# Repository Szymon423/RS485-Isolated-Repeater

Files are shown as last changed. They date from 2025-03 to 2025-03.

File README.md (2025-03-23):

# RS485 Isolated Repeater

This project is abotut designing an isolated repeater for RS485 communication. As a person who many times had to deal with RS485 communication, I know how important it is to have a repeater in order to extend the communication distance. However, I also know how important it is to have an isolated repeater in order to avoid ground loops and other issues that can arise from non-isolated repeaters. This project is about designing an isolated repeater that can be used to extend the communication distance of RS485 devices. The repeater is designed to be used with a `12..24V` power supply and can be used to extend the communication distance up to 1000 meters. 

> [!IMPORTANT]
> Chad GPT is amazing and made up this trash talk above.

To be honest this is not about extending range of RS485 loop, even though it can be used for that. It is about isolating the RS485 devices which are shitty and can cause problems. 

> [!NOTE]
> I want to help people who made shitty RS485 bus or RS485 devices.

## Tools stack
- Hardware design: `KiCad`
- PCB manufacturing: `JLCPCB`
- Microcontroller code: `Raspberry Pi Pico Extension for VSCode`
- Knowledge: `IDK`

## Hardware
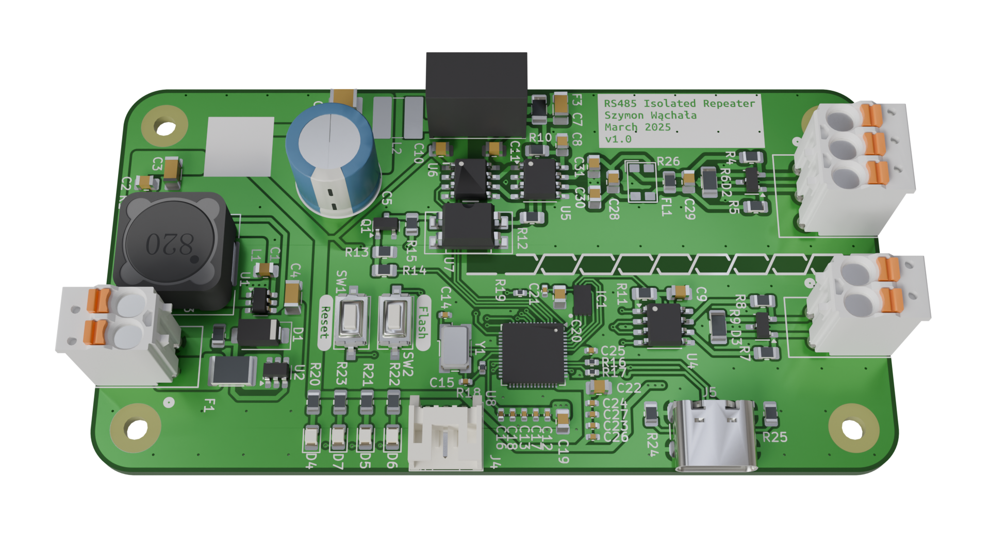
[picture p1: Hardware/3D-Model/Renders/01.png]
PCB render


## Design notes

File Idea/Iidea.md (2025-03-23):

# Must have
 - Single power supply `12..24VDC`
 - One RS485 port must be galvanicly isolated
 - Onboard isolated voltage regulator `3.3VDC`
 - Auto adaptation to: 
    - baudrate `9600..115200 bps`
    - parity `none, even, odd`
    - stop bits `1, 2`
    - data bits `8, 7`
 - LED showing power supply
 - LEDs showing communication direction
 - LED showing errors in communication - both sides are beeing driven in the same time

# Components
 - [Texas Instruments ISO1410DW](https://www.tme.eu/pl/details/iso1410dw/uklady-scalone-rs232-rs422-rs485/texas-instruments/) - isolated RS485 transceiver
 - [Texas Instruments THVD1400DR](https://www.tme.eu/pl/details/thvd1400dr/uklady-scalone-rs232-rs422-rs485/texas-instruments/) - non-isolated RS485 transceiver
 - [AIMTEC AM1S-0303SH30Z](https://www.tme.eu/pl/details/am1s-0303sh30z/przetwornice-dc-dc/aimtec/) - 3.3VDC isolated voltage regulator
 - [Texas Instruments TPS54202DDCR](https://www.tme.eu/pl/details/tps54202ddcr/regulatory-napiecia-uklady-dc-dc/texas-instruments/) - 3.3VDC non-isolated voltage regulator
 - [Raspberry RP2040](https://www.tme.eu/pl/details/sc0914-7/raspberry-pi-embedded/raspberry-pi/ic-rp2040-rp2b2-t-r-500-7-reel/) - microcontroller
 - [Winbond W25Q16JVUXIQ TR](https://www.tme.eu/pl/details/w25q16jvuxiq-tr/pamieci-flash-szeregowe/winbond/w25q16jvuxiq-tr/) - flash memory
 - [Abracon ABM8-272-T3](https://mou.sr/4bnWQzx) - Crystal oscillator
 - [Ferrocore 18uH 0504](https://www.tme.eu/pl/details/dlg-0504-180/dlawiki-smd-mocy/ferrocore/)

# Schematics 

**12..24VDC to 3.3VDC**
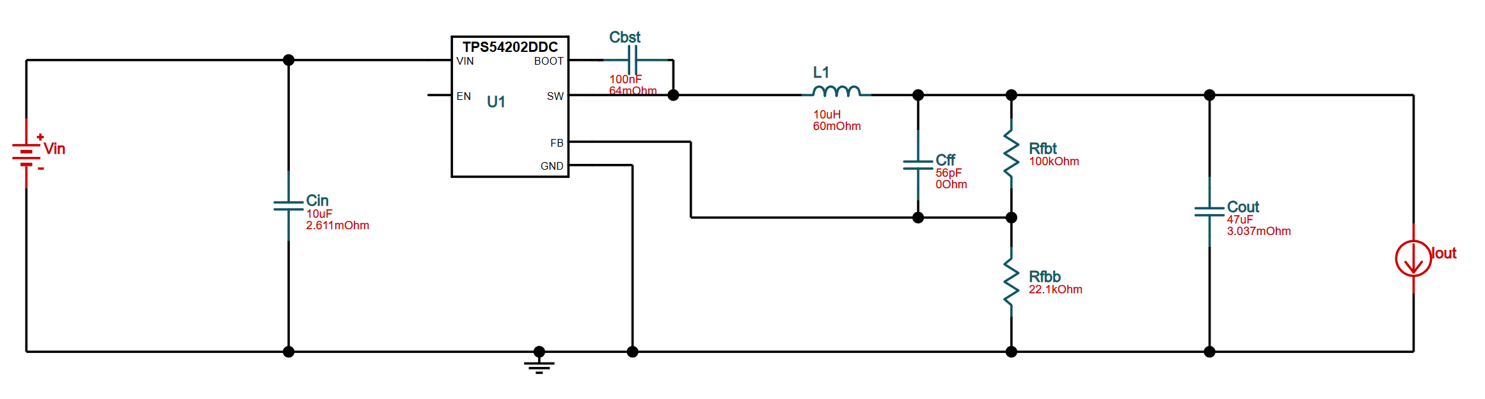
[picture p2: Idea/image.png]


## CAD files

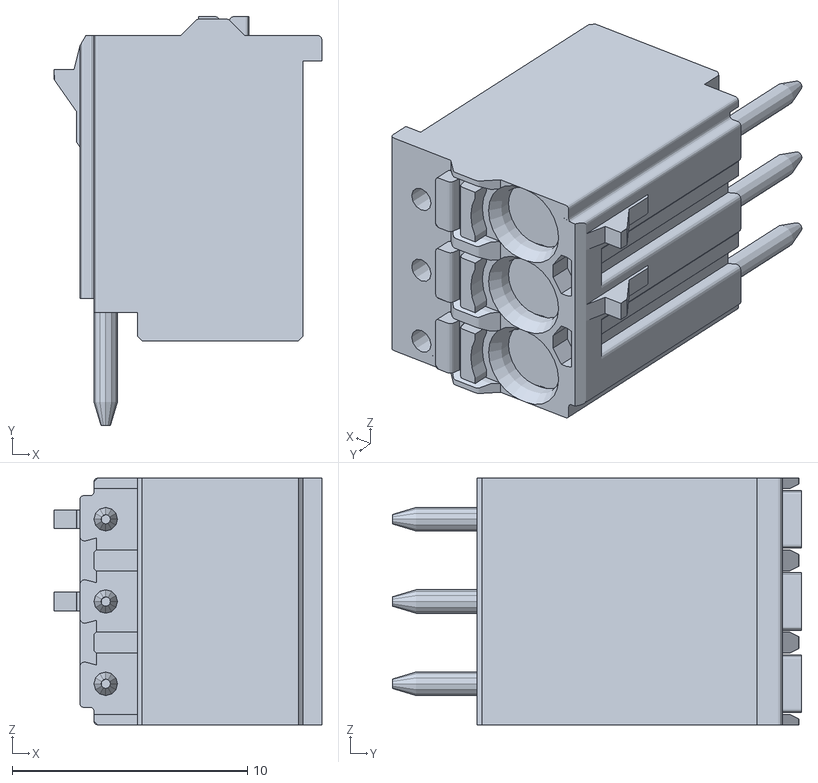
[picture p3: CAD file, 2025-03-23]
Hardware/3D-Model/Assets/2091-1173.obj
11.4 x 17.4 x 10.5

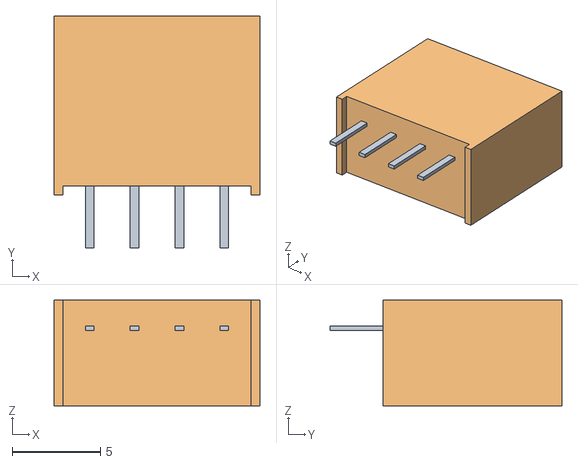
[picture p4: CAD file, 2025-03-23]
Hardware/3D-Model/Assets/AM1S-Z.obj
11.7 x 13.1 x 6.00
obj1
obj2

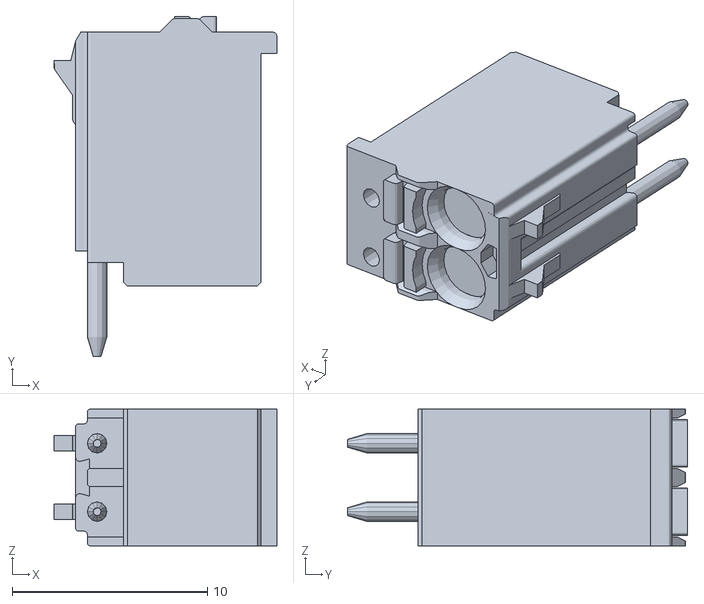
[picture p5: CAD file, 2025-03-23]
Hardware/3D-Model/Assets/2091-1172.obj
11.4 x 17.4 x 7.00

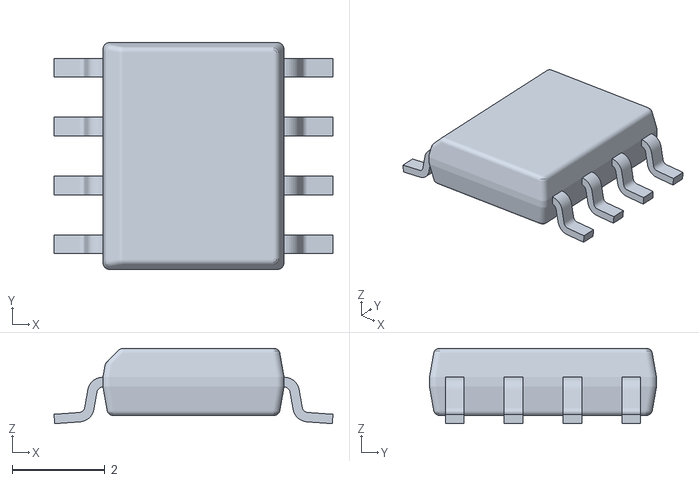
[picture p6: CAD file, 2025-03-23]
Hardware/3D-Model/Assets/ISO7721D.stl
6.02 x 4.90 x 1.63

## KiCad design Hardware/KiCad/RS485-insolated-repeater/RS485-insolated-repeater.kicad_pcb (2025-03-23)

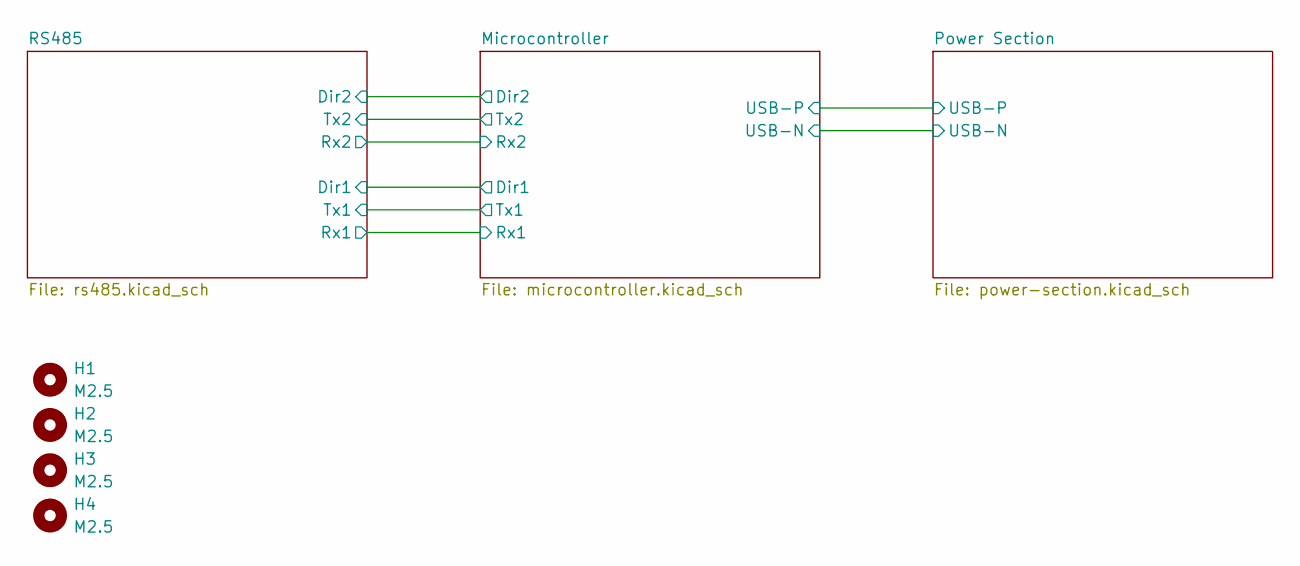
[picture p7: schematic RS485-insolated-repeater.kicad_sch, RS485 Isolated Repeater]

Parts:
H1, H2, H3, H4: M2.5; MountingHole_2.7mm_M2.5

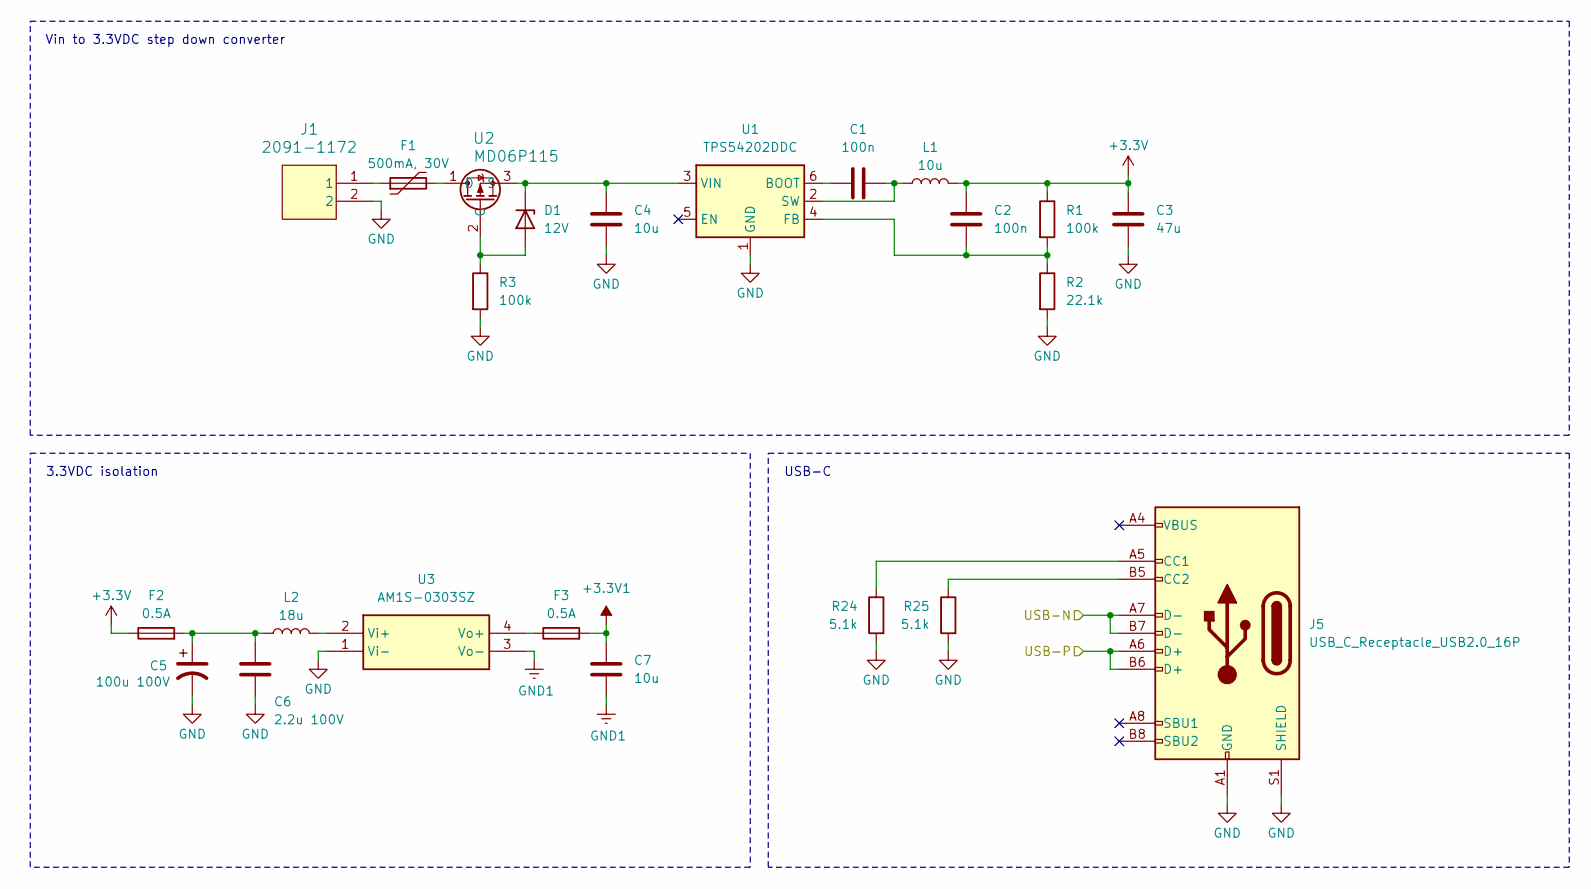
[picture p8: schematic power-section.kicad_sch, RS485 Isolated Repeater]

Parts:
C1, C2: 100n; C_0805_2012Metric
C3: 47u; C_1206_3216Metric
C4, C7: 10u; C_1206_3216Metric
C5: 100u 100V; CP_Radial_D10.0mm_P5.00mm
C6: 2.2u 100V; C_1210_3225Metric
D1: 12V; D_SMA
F1: 500mA, 30V; Fuse_1812_4532Metric
F2, F3: 0.5A; Fuse_1206_3216Metric
J1: 2091-1172
J5: USB_C_Receptacle_USB2.0_16P; USB_C_Receptacle_GCT_USB4105-xx-A_16P_TopMnt_Horizontal
L1: 10u; L_12x12mm_H4.5mm
L2: 18u; L_Ferrocore_DLG-0504
R1, R3: 100k; R_0805_2012Metric
R2: 22.1k; R_0805_2012Metric
R24, R25: 5.1k; R_0805_2012Metric
U1: TPS54202DDC; SOT-23-6
U2: MD06P115
U3: AM1S-0303SZ; SON50P300X200X60-9N; Manufacturer_Part_Number W25Q16JVUXIQ TR

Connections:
+3.3V: C2.2, C3.2, F2.1, L1.2, R1.1; also elsewhere on the board
+3.3V1: C7.2, F3.2; also elsewhere on the board
/Microcontroller/USB-N: J5.A7 (D-), J5.B7 (D-); also elsewhere on the board
/Microcontroller/USB-P: J5.A6 (D+), J5.B6 (D+); also elsewhere on the board
GND: C3.1, C4.1, C5.2, C6.2, J1.2, J5.A1 (GND), J5.A12 (GND), J5.B1 (GND), J5.B12 (GND), J5.S1 (SHIELD), R2.2, R3.2, R24.2, R25.2, U1.1 (GND), U3.1 (Vi-); also elsewhere on the board
GND1: C7.1, U3.3 (Vo-); also elsewhere on the board
unnamed: C5.1, C6.1, F2.2, L2.1
unnamed: D1.2 (A), R3.1, U2.2 (G)
unnamed: C4.2, D1.1 (K), U1.3 (VIN), U2.3 (S)
unnamed: F1.1, J1.1
unnamed: J5.A5 (CC1), R24.1
unnamed: J5.B5 (CC2), R25.1
unnamed: C1.1, U1.6 (BOOT)
unnamed: C2.1, R1.2, R2.1, U1.4 (FB)
unnamed: C1.2, L1.1, U1.2 (SW)
unnamed: F1.2, U2.1 (D)
unnamed: L2.2, U3.2 (Vi+)
unnamed: F3.1, U3.4 (Vo+)

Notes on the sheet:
Vin to 3.3VDC step down converter
USB-C
3.3VDC isolation

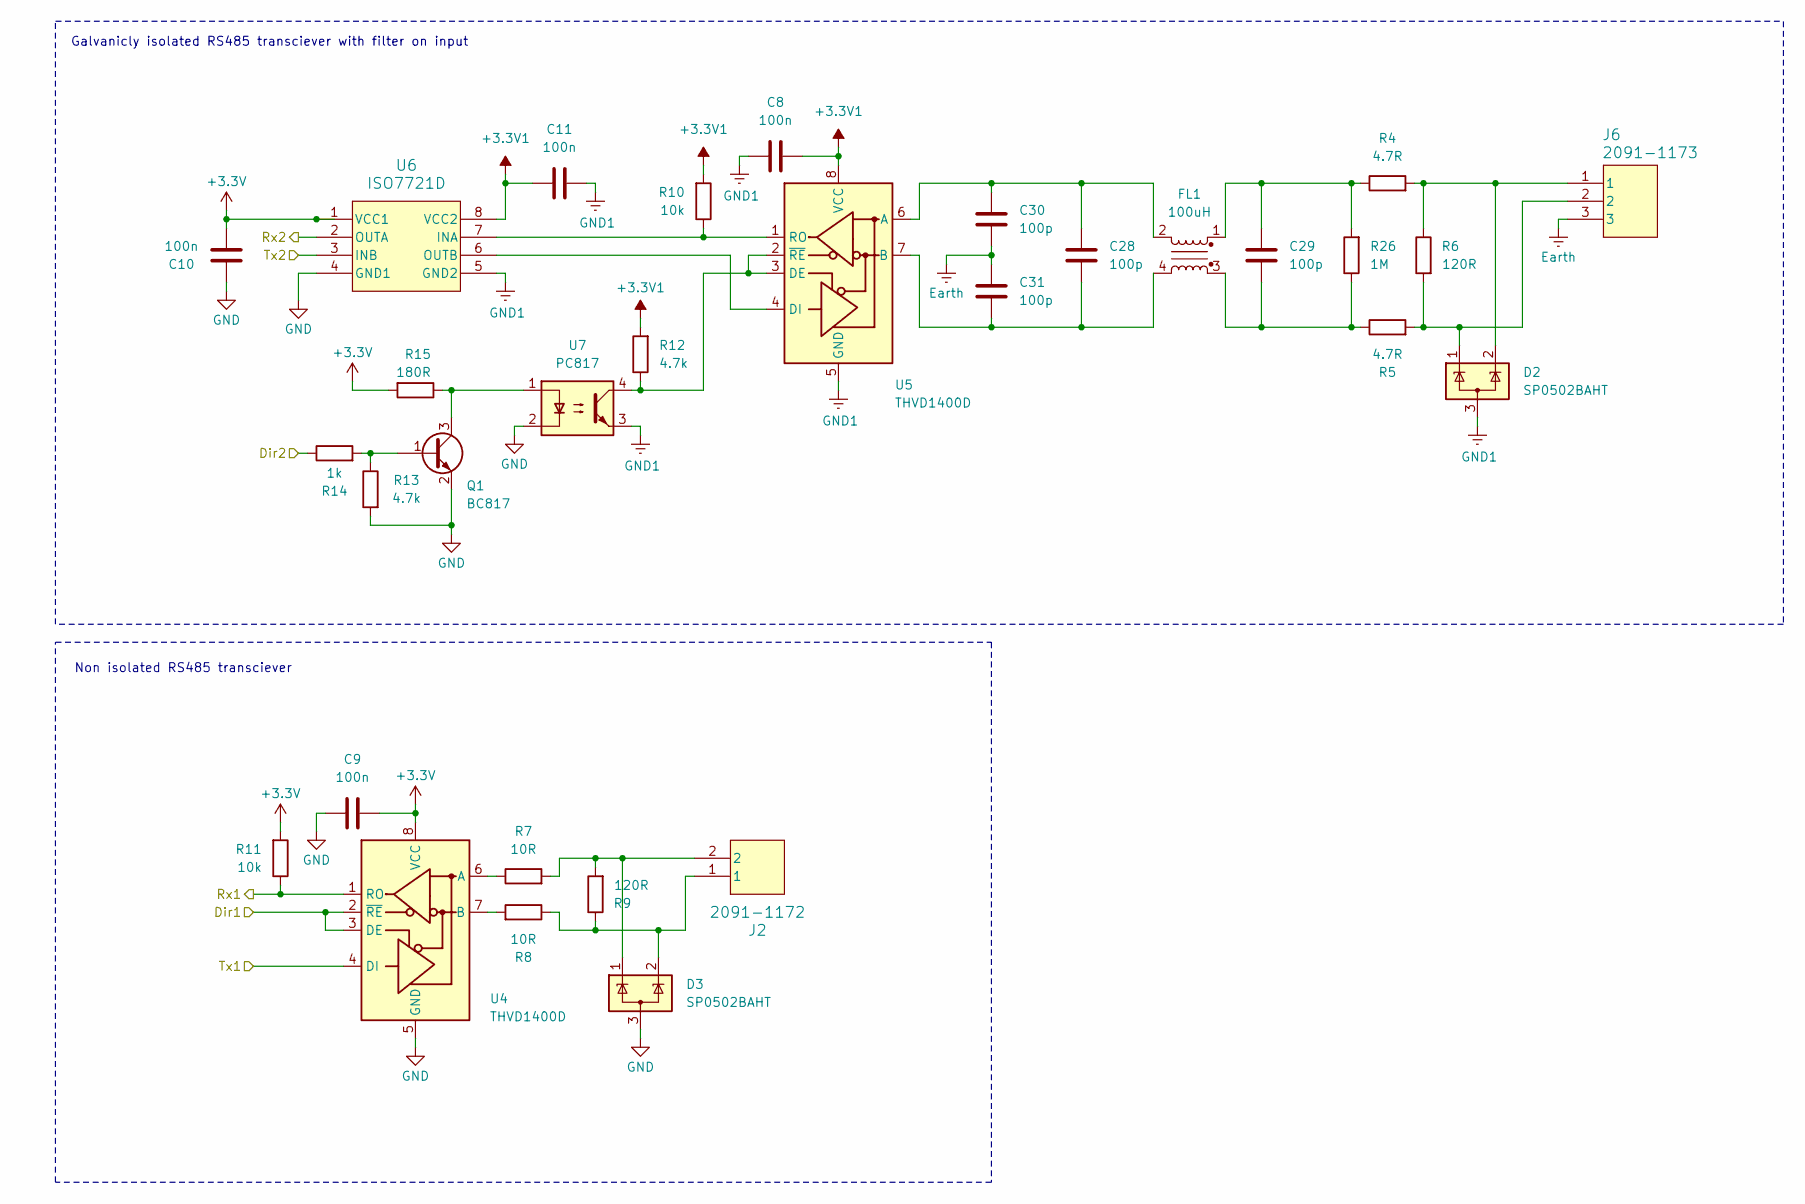
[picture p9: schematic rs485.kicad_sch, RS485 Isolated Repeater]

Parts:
C8, C9, C10, C11: 100n; C_0805_2012Metric
C28, C29, C30, C31: 100p; C_0805_2012Metric
D2, D3: SP0502BAHT; SOT-23-3
FL1: 100uH; L_CommonModeChoke_Coilcraft_1812CAN
J2: 2091-1172
J6: 2091-1173
Q1: BC817; SOT-23
R4, R5: 4.7R; R_0805_2012Metric
R6, R9: 120R; R_1206_3216Metric
R7, R8: 10R; R_0805_2012Metric
R10, R11: 10k; R_0805_2012Metric
R12, R13: 4.7k; R_0805_2012Metric
R14: 1k; R_0805_2012Metric
R15: 180R; R_0805_2012Metric
R26: 1M; R_0805_2012Metric
U4, U5: THVD1400D; SOIC-8_3.9x4.9mm_P1.27mm
U6: ISO7721D
U7: PC817; DIP-4_W7.62mm_SMDSocket_SmallPads

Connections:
+3.3V: C9.2, C10.1, R11.2, R15.2, U4.8 (VCC), U6.1 (VCC1); also elsewhere on the board
+3.3V1: C8.2, C11.1, R10.2, R12.2, U5.8 (VCC), U6.8 (VCC2); also elsewhere on the board
/Microcontroller/Dir1: U4.2 (~RE), U4.3 (DE); also elsewhere on the board
/Microcontroller/Dir2: R14.1; also elsewhere on the board
/Microcontroller/Rx1: R11.1, U4.1 (RO); also elsewhere on the board
/Microcontroller/Rx2: U6.2 (OUTA); also elsewhere on the board
/Microcontroller/Tx1: U4.4 (DI); also elsewhere on the board
/Microcontroller/Tx2: U6.3 (INB); also elsewhere on the board
Earth: C30.1, C31.2, J6.3
GND: C9.1, C10.2, D3.3 (A), Q1.2 (E), R13.2, U4.5 (GND), U6.4 (GND1), U7.2; also elsewhere on the board
GND1: C8.1, C11.2, D2.3 (A), U5.5 (GND), U6.5 (GND2), U7.3; also elsewhere on the board
unnamed: C29.1, FL1.3, R5.1, R26.1
unnamed: C29.2, FL1.1, R4.1, R26.2
unnamed: D2.1 (K), J6.2, R5.2, R6.2
unnamed: D2.2 (K), J6.1, R4.2, R6.1
unnamed: D3.1 (K), J2.2, R7.2, R9.2
unnamed: D3.2 (K), J2.1, R8.1, R9.1
unnamed: Q1.1 (B), R13.1, R14.2
unnamed: Q1.3 (C), R15.1, U7.1
unnamed: R7.1, U4.6 (A)
unnamed: R8.2, U4.7 (B)
unnamed: C28.2, C30.2, FL1.2, U5.6 (A)
unnamed: C28.1, C31.1, FL1.4, U5.7 (B)
unnamed: R12.1, U5.2 (~RE), U5.3 (DE), U7.4
unnamed: U5.4 (DI), U6.6 (OUTB)
unnamed: R10.1, U5.1 (RO), U6.7 (INA)

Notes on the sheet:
Non isolated RS485 transciever
Galvanicly isolated RS485 transciever with filter on input

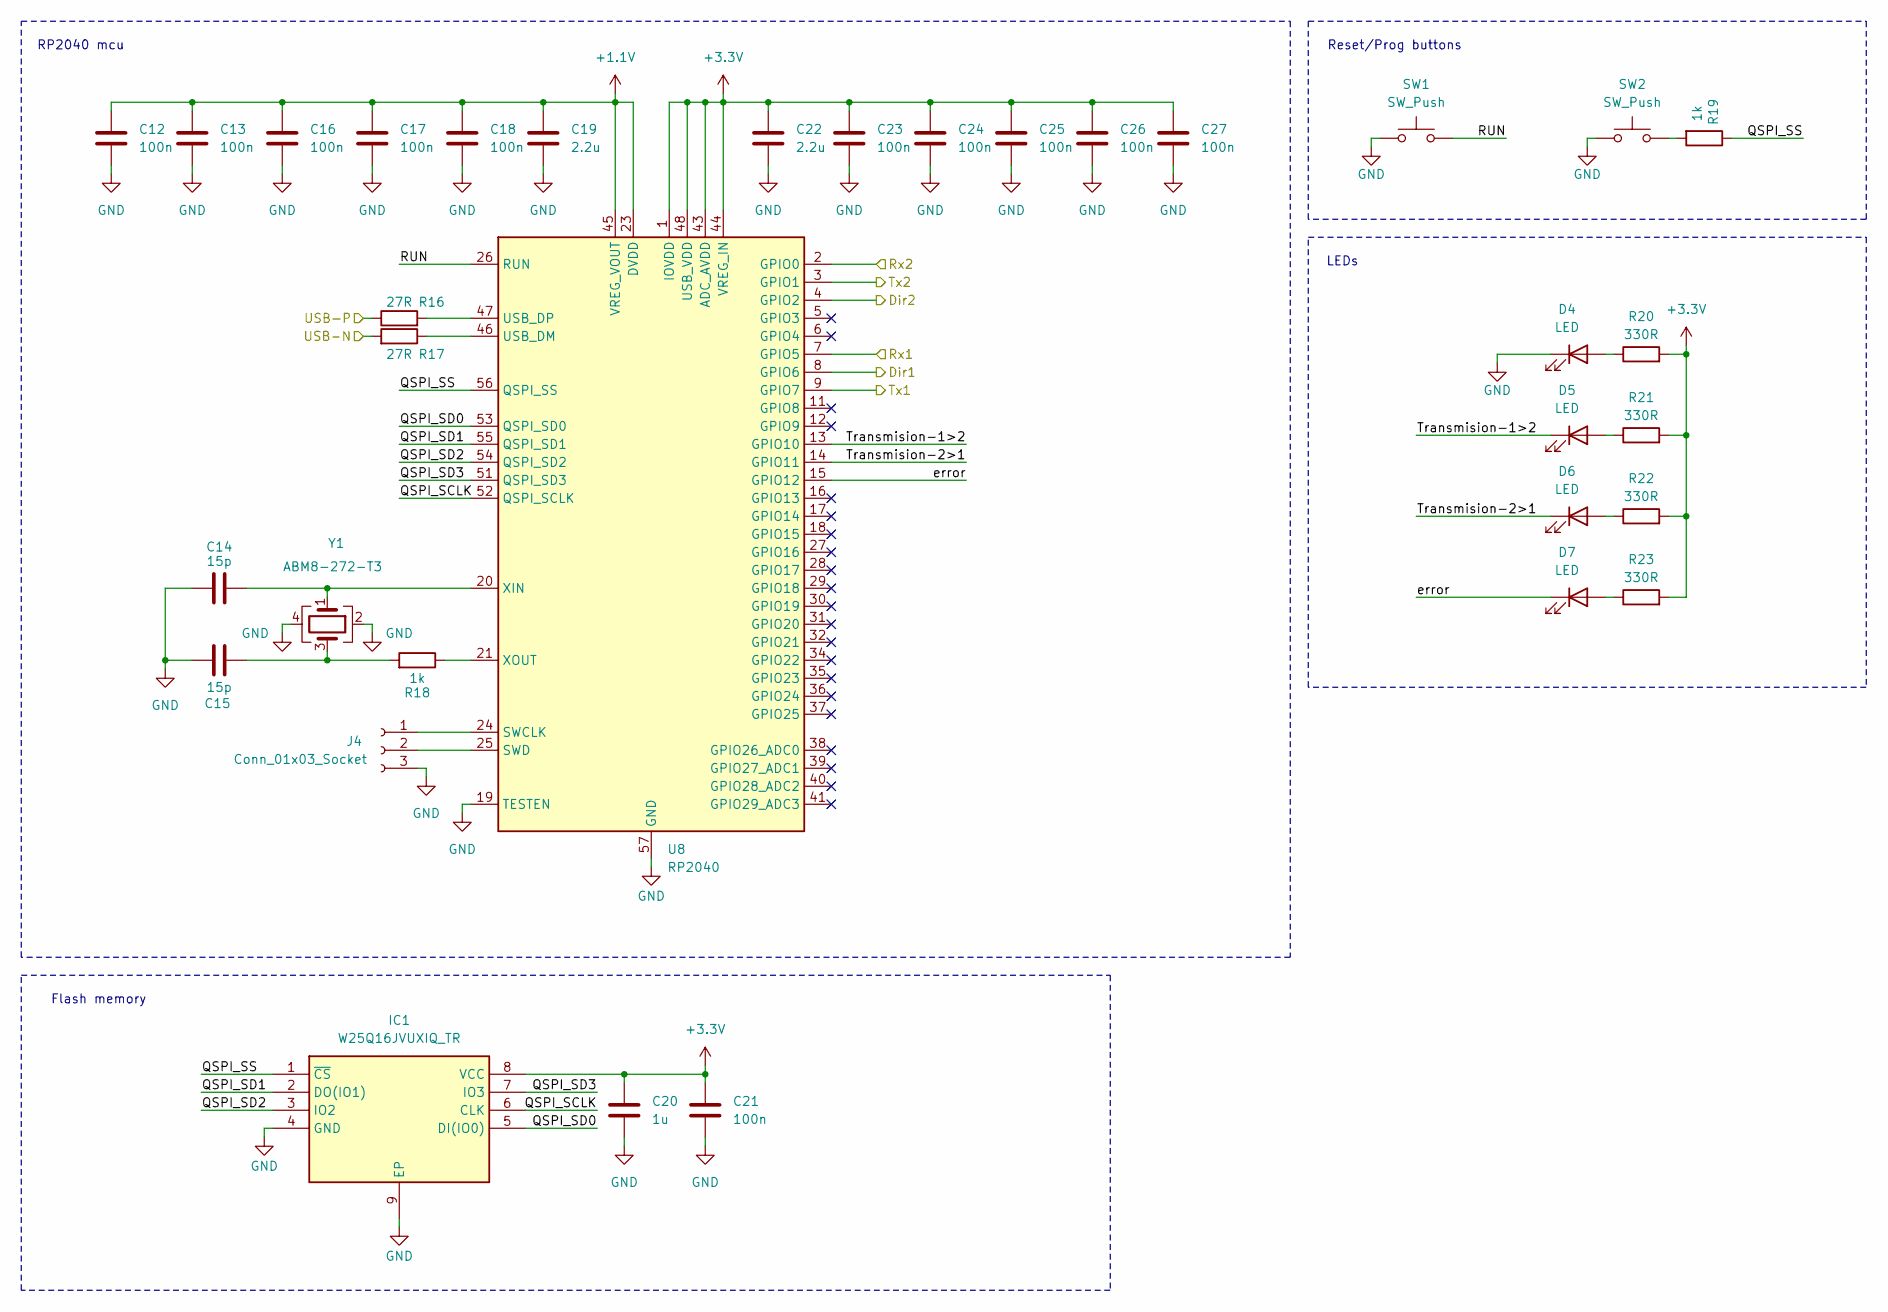
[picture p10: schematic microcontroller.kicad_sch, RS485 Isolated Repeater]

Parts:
C12, C13, C16, C17, C18, C21, C23, C24, C25, C26, C27: 100n; C_0402_1005Metric
C14, C15: 15p; C_0402_1005Metric
C19, C22: 2.2u; C_0805_2012Metric
C20: 1u; C_0805_2012Metric
D4, D5, D6, D7: LED; LED_0805_2012Metric
IC1: W25Q16JVUXIQ_TR; SON50P300X200X60-9N; Manufacturer_Part_Number W25Q16JVUXIQ TR
J4: Conn_01x03_Socket; JST_PH_S3B-PH-K_1x03_P2.00mm_Horizontal
R16, R17: 27R; R_0402_1005Metric
R18, R19: 1k; R_0402_1005Metric
R20, R21, R22, R23: 330R; R_0805_2012Metric
SW1, SW2: SW_Push; SW_Tactile_SPST_NO_Straight_CK_PTS636Sx25SMTRLFS
U8: RP2040; QFN-56-1EP_7x7mm_P0.4mm_EP3.2x3.2mm_ThermalVias
Y1: ABM8-272-T3; Crystal_SMD_Abracon_ABM3B-4Pin_5.0x3.2mm

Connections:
+1.1V: C12.1, C13.1, C16.1, C17.1, C18.1, C19.1, U8.23 (DVDD), U8.45 (VREG_VOUT), U8.50 (DVDD)
+3.3V: C20.1, C21.1, C22.1, C23.1, C24.1, C25.1, C26.1, C27.1, IC1.8 (VCC), R20.2, R21.2, R22.2, R23.2, U8.1 (IOVDD), U8.10 (IOVDD), U8.22 (IOVDD), U8.33 (IOVDD), U8.42 (IOVDD), U8.43 (ADC_AVDD), U8.44 (VREG_IN), U8.48 (USB_VDD), U8.49 (IOVDD); also elsewhere on the board
/Microcontroller/Dir1: U8.8 (GPIO6); also elsewhere on the board
/Microcontroller/Dir2: U8.4 (GPIO2); also elsewhere on the board
/Microcontroller/QSPI_SCLK: IC1.6 (CLK), U8.52 (QSPI_SCLK)
/Microcontroller/QSPI_SD0: IC1.5 (DI(IO0)), U8.53 (QSPI_SD0)
/Microcontroller/QSPI_SD1: IC1.2 (DO(IO1)), U8.55 (QSPI_SD1)
/Microcontroller/QSPI_SD2: IC1.3 (IO2), U8.54 (QSPI_SD2)
/Microcontroller/QSPI_SD3: IC1.7 (IO3), U8.51 (QSPI_SD3)
/Microcontroller/QSPI_SS: IC1.1 (~CS), R19.1, U8.56 (QSPI_SS)
/Microcontroller/RUN: SW1.2, U8.26 (RUN)
/Microcontroller/Rx1: U8.7 (GPIO5); also elsewhere on the board
/Microcontroller/Rx2: U8.2 (GPIO0); also elsewhere on the board
/Microcontroller/Transmision-1>2: D5.1 (K), U8.13 (GPIO10)
/Microcontroller/Transmision-2>1: D6.1 (K), U8.14 (GPIO11)
/Microcontroller/Tx1: U8.9 (GPIO7); also elsewhere on the board
/Microcontroller/Tx2: U8.3 (GPIO1); also elsewhere on the board
/Microcontroller/USB-N: R17.2; also elsewhere on the board
/Microcontroller/USB-P: R16.1; also elsewhere on the board
/Microcontroller/error: D7.1 (K), U8.15 (GPIO12)
GND: C12.2, C13.2, C14.1, C15.1, C16.2, C17.2, C18.2, C19.2, C20.2, C21.2, C22.2, C23.2, C24.2, C25.2, C26.2, C27.2, D4.1 (K), IC1.4 (GND), IC1.9 (EP), J4.3, SW1.1, SW2.1, U8.19 (TESTEN), U8.57 (GND), Y1.2, Y1.4; also elsewhere on the board
unnamed: C15.2, R18.2, Y1.3
unnamed: D4.2 (A), R20.1
unnamed: D5.2 (A), R21.1
unnamed: D6.2 (A), R22.1
unnamed: D7.2 (A), R23.1
unnamed: J4.1, U8.24 (SWCLK)
unnamed: J4.2, U8.25 (SWD)
unnamed: R19.2, SW2.2
unnamed: R17.1, U8.46 (USB_DM)
unnamed: R16.2, U8.47 (USB_DP)
unnamed: C14.2, U8.20 (XIN), Y1.1
unnamed: R18.1, U8.21 (XOUT)

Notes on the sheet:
LEDs
Reset/Prog buttons
RP2040 mcu
Flash memory

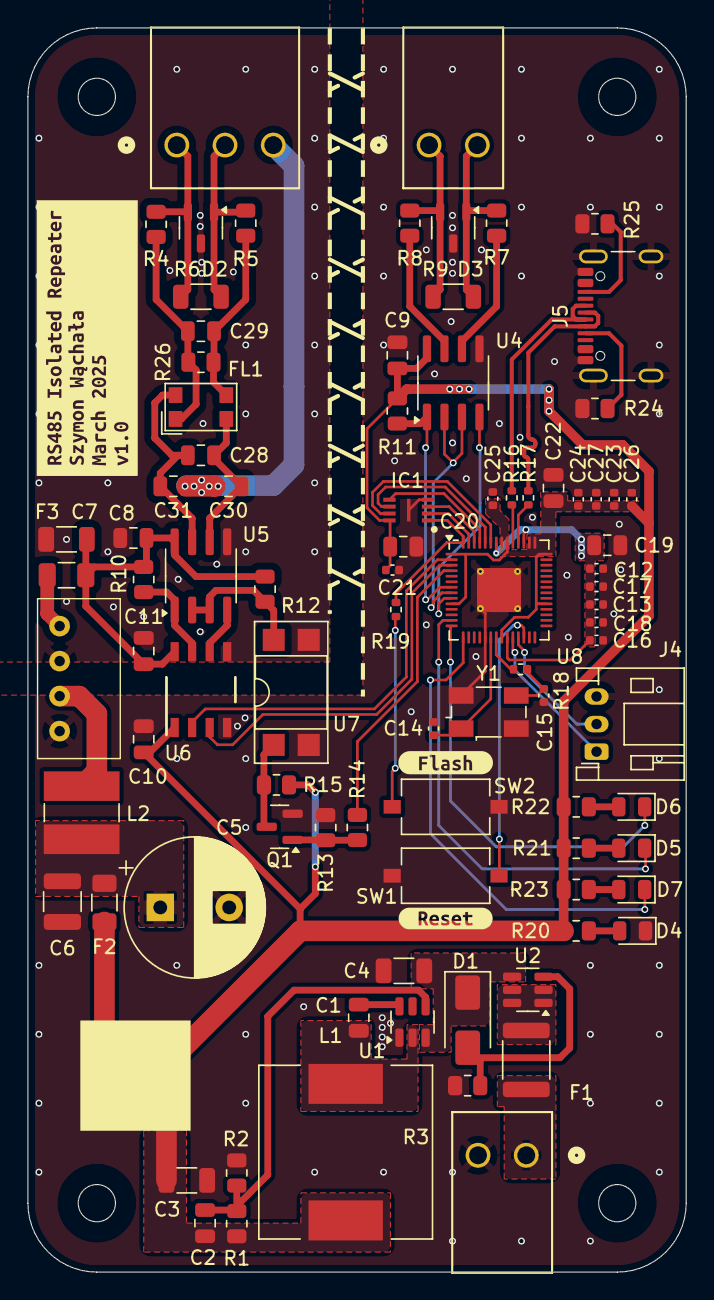
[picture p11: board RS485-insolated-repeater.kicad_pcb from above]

Board: 2 copper layers, 47.7 x 90.2 mm, 95 parts (0 on the bottom side), 63 nets.

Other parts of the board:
kibuzzard-67E01B78: G***; kibuzzard-67E01B78
kibuzzard-67E01C2F: G***; kibuzzard-67E01C2F
kibuzzard-67E01C3D: G***; kibuzzard-67E01C3D

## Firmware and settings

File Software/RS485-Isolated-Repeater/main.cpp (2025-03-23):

#include <stdio.h>
#include "pico/stdlib.h"
#include "hardware/watchdog.h"
#include "definitions.hpp"
#include "interrupts.hpp"
#include "gpio.hpp"
#include "rs485.hpp"

int main() {
    // Initialize the stdio system
    stdio_init_all();

    // Actions needed when reboot was caused by the watchdog
    if (watchdog_caused_reboot()) {
        // Do I need to make something here?
    }

    // Initlize the GPIO pins
    GPIO::Initialize();

    // Initialize interrupts
    Interrupts::Initialize();

    // Initialize RS485
    RS485::Initialize();

    // Enable the watchdog, requiring the watchdog to be updated every 100ms or the chip will reboot
    // TODO: second arg is pause on debug which means the watchdog will pause when stepping through code
    watchdog_enable(100, 1);
    
    // You need to call this function at least more often than the 100ms in the enable call to prevent a reboot
    watchdog_update();

    while (true) {
        printf("Hello, world!\n");
        sleep_ms(1000);
    }
}

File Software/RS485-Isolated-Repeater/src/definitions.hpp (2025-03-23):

#pragma once
#include <pico/stdlib.h>

/// @brief Namespace for all definitions
namespace Definitions {
    // Define pins for isolated RS485 interface
    constexpr uint8_t RS485RxIsolatedPin = 0;
    constexpr uint8_t RS485TxIsolatedPin = 1;
    constexpr uint8_t RS485DirIsolatedPin = 2;

    // Define pins for non isolated RS485 interface
    constexpr uint8_t RS485RxPin = 5;
    constexpr uint8_t RS485TxPin = 6;
    constexpr uint8_t RS485DirPin = 7;

    // Define pins for LEDs
    constexpr uint8_t LedToIsolatedPin = 10;
    constexpr uint8_t LedFromIsolatedPin = 11;
    constexpr uint8_t LedErrorPin = 12 ;
}

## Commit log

2025-03-23 Added renders
    [2091-1173.obj, AM1S-Z.obj]
2025-03-23 Started writing code - gpio, interrupts
